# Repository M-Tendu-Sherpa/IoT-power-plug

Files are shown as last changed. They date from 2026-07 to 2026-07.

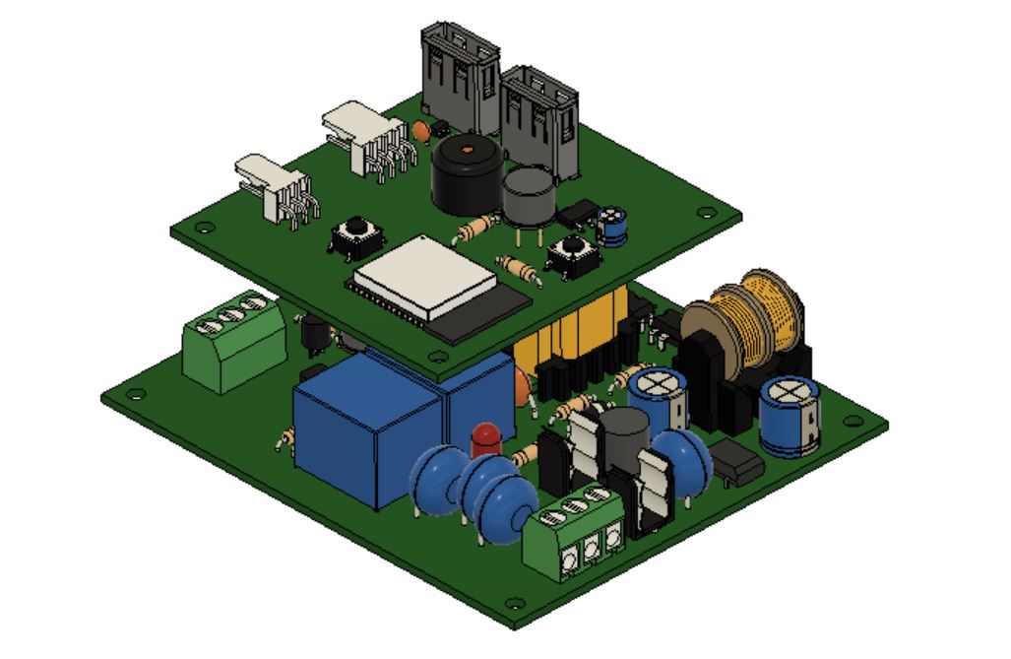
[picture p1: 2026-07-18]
Render images 3D/PCB_assembly.JPG

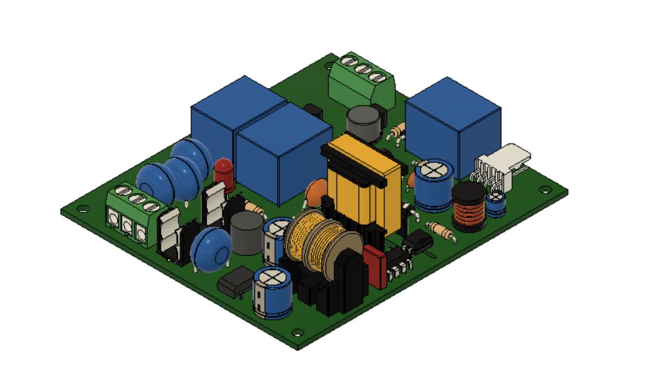
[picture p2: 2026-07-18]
Render images 3D/Bottom_PCB.JPG

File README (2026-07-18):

This project was done as a freelance project where I was paid to design the electrical aspects for the IoT smart plug,
which included schematics, component selection, BOM, PCB design, and 3D design.
The circuit is designed to fetch the weather data from the internet and monitor the lightening hazard.
Under severe weather conditions the plug would disconned the power from all the appliances connected through it,
hence ensuring electrical safety.

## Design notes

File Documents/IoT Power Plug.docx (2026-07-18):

IoT Power Plug

The IoT power plug with the ESP32 chip ensures protection of the devices connected to its extensions. The extensions included supports two 110VAC and 5VDC based devices each.

The ESP32 chip works with both WiFi and Bluetooth Low Energy (BLE) and is more stable and advanced than any other IoT microcontrollers. Here in this product, the ESP32 WROOM 32 chip suits best considering all our requirements. The overall product is equipped with surge protector (triple MOV configuration) and a FUSE to ensure superior safety. Similarly, when the ESP turns off the power supply to the extension plugs, the relay configuration completely isolates the devices connected to the extension from the main power line. The power plug also includes a buzzer module controlled by the ESP chip and a 15 Watt DC power supply to power the overall control system and the 5VDC power extension.

Block Diagram

Signal flow

Power flow

To extension

110V AC

Buzzer Module

ESP32

Relay Module

Surge Protection

SMPS 15W

3.3V Regulator

Schematic diagram

The PCB is designed in two layers: the bottom layer and the top layer. The significance of this design method is to isolate the AC circuits from the delicate DC circuits. Besides that, stacking the PCB one above another serves for compact design of the product. The schematic of each layer is shown below with the description of the functional units it includes.

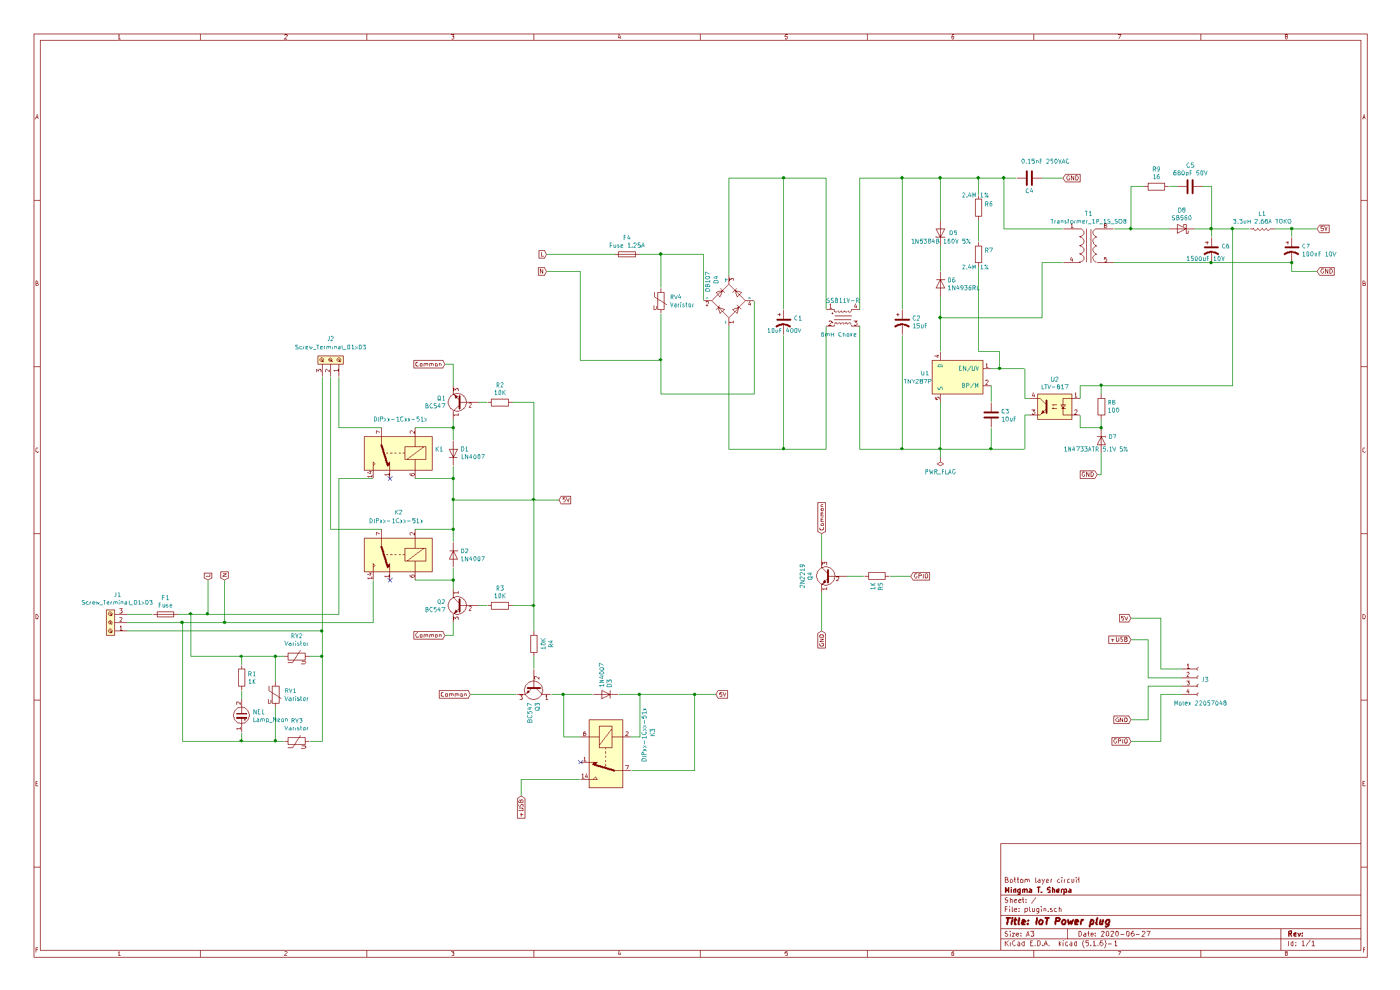
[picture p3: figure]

FIG: Schematic of the bottom layer PCB

The above schematic includes the following functional units:

1. Triple surge protection with FUSE
2. Relay configuration for switching the power to extensions
3. 15W SMPS DC power supply
4. Connectors for power and ESP32.

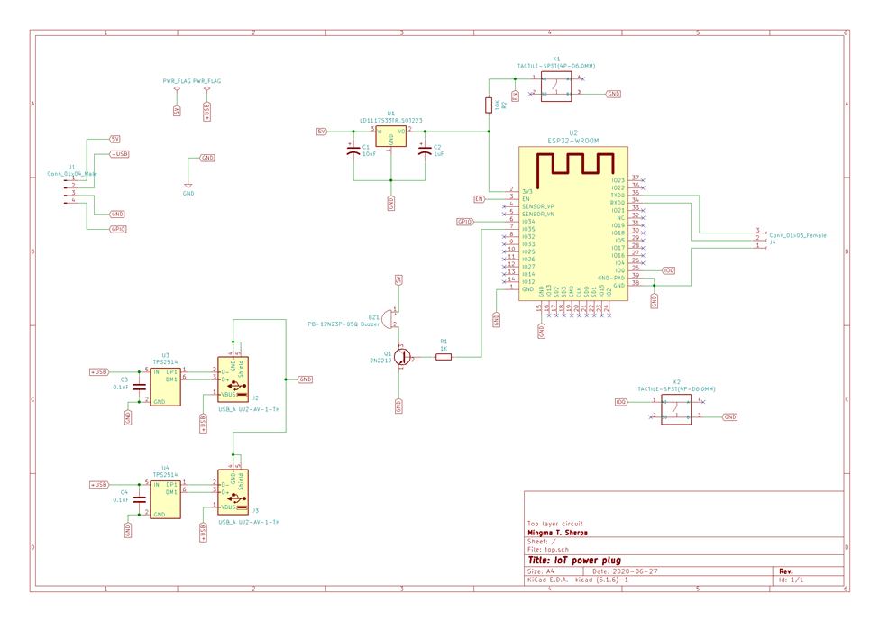
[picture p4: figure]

FIG: Schematic of the top layer PCB

The above schematic includes the following functional units:

1. ESP32
2. 3.3V DC power regulator for ESP32
3. Two 5VDC USB outlets
4. Buzzer module
5. Connectors for power and ESP32

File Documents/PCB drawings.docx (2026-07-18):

DRAWINGS

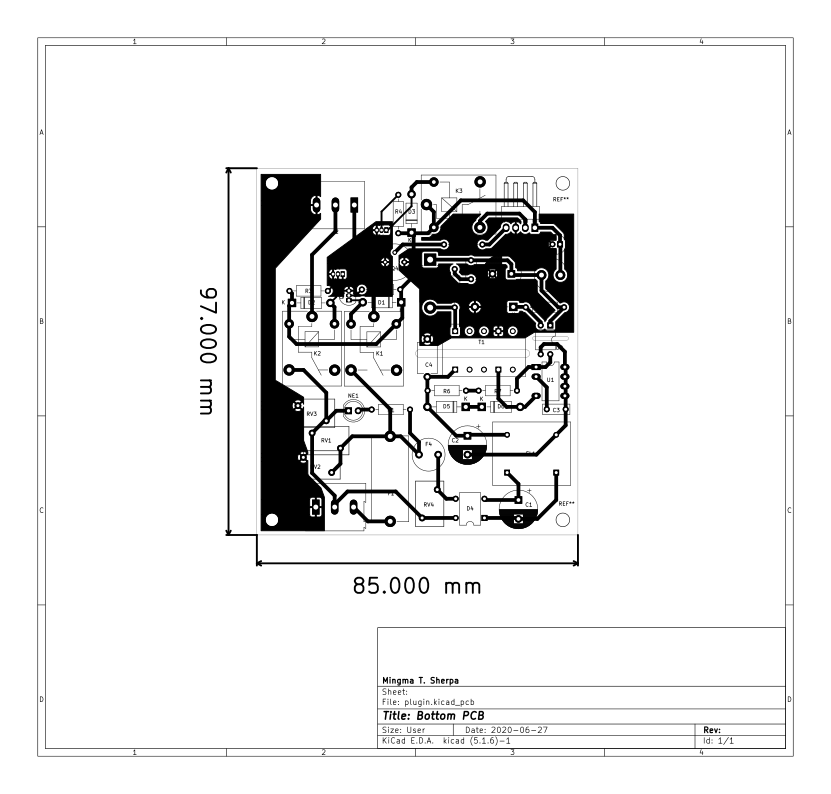
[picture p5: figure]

Fig 1.1: Bottom layer PCB layout

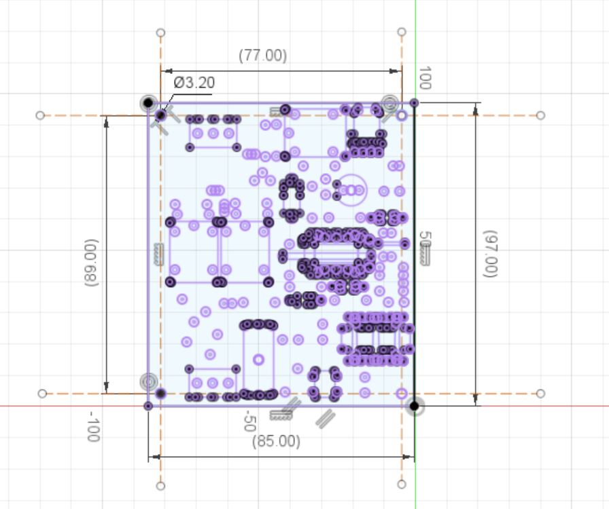
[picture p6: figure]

Fig 1.2: Bottom layer PCB dimensions

Above figures includes dimensions of the board along with edge cuts and drill holes. The drill holes are made compatible for M3 screws.

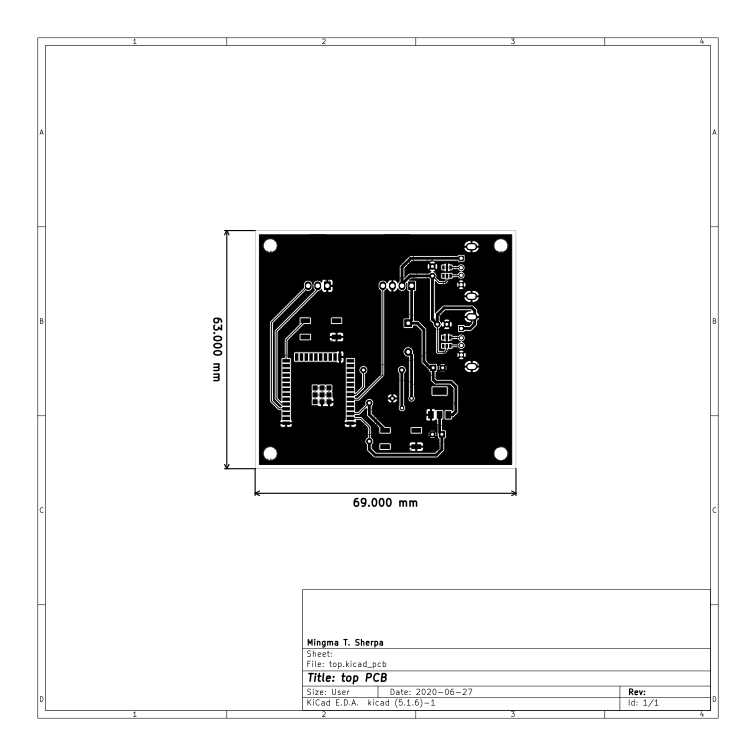
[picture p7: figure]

Fig 2.1: Top layer PCB layout

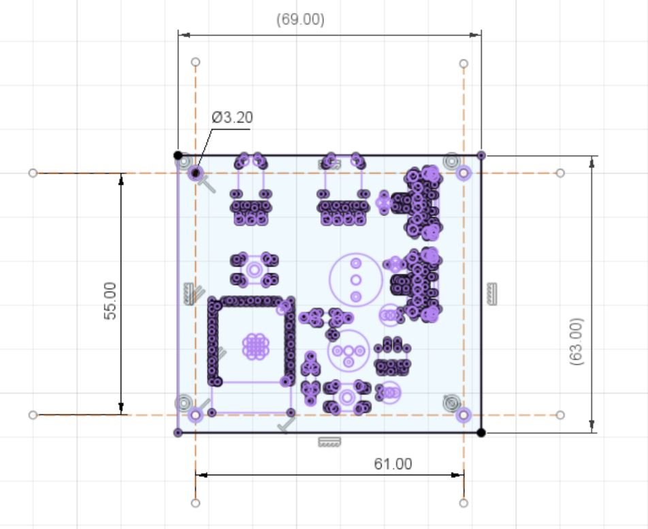
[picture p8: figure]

Fig 2.2: Top layer PCB dimensions

Above figures includes the dimensions of the board with all necessary masks (similar in Fig 1). The screw used are the M3 standard as in Bottom layer PCB.

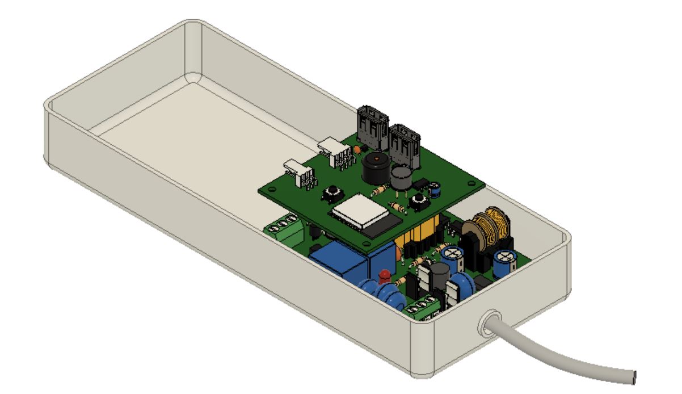
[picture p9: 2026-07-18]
Render images 3D/Within_case1.JPG

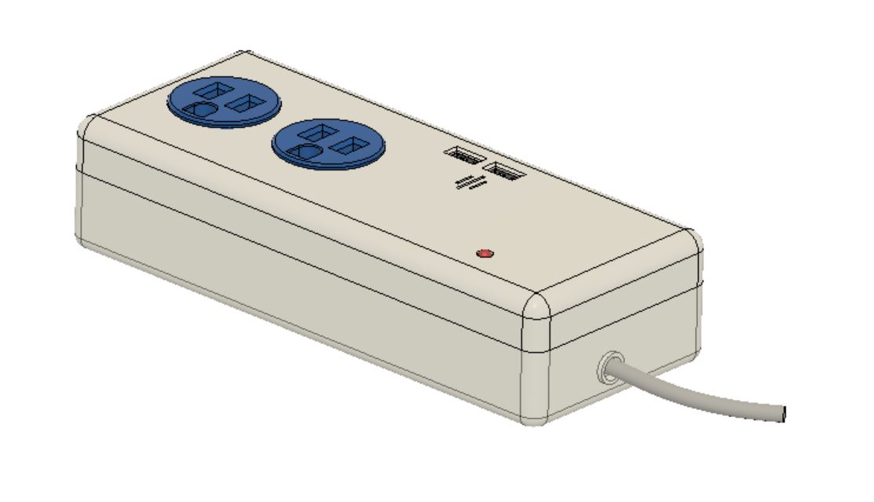
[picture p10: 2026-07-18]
Render images 3D/Within_case2.JPG

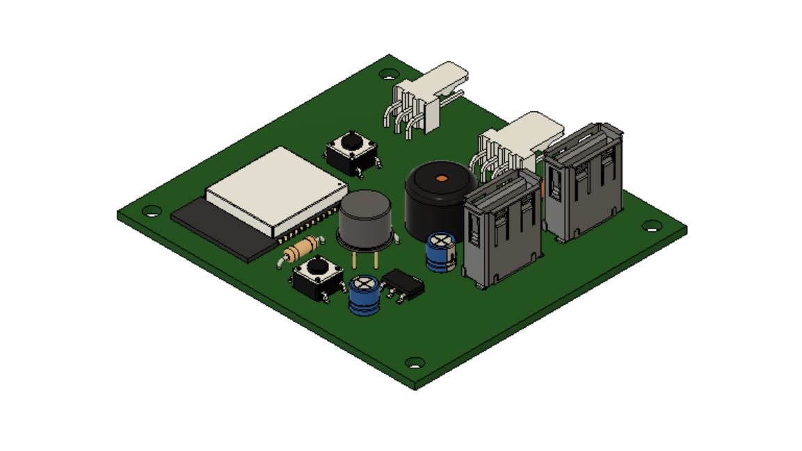
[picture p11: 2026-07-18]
Render images 3D/Top_PCB.JPG

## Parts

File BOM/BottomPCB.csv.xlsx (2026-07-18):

Source: | Bottom layer circuit
Date: | 2020-06-27 11:53
Tool: | Eeschema (5.1.6)-1
Component Count: | 46
Ref | Value | Footprint | Datasheet | Manufacturer | Vendor
C1 | 10uF 400V | Capacitor_THT:CP_Radial_D10.0mm_P5.00mm | ~
C2 | 15uF | Capacitor_THT:CP_Radial_D10.0mm_P5.00mm | ~
C3 | 10uF | Capacitor_THT:C_Rect_L7.0mm_W2.5mm_P5.00mm | ~
C4 | 0.15nF 250VAC | Capacitor_THT:C_Disc_D8.0mm_W5.0mm_P10.00mm | ~
C5 | 680pF 50V | Capacitor_THT:C_Disc_D5.0mm_W2.5mm_P5.00mm | ~
C6 | 1500uF 10V | Capacitor_THT:CP_Radial_D10.0mm_P5.00mm | ~
C7 | 100uF 10V | Capacitor_THT:CP_Radial_D5.0mm_P2.00mm | ~
D1 | 1N4007 | Diode_THT:D_DO-41_SOD81_P10.16mm_Horizontal | http://www.vishay.com/docs/88503/1n4001.pdf
D2 | 1N4007 | Diode_THT:D_DO-41_SOD81_P10.16mm_Horizontal | http://www.vishay.com/docs/88503/1n4001.pdf
D3 | 1N4007 | Diode_THT:D_DO-41_SOD81_P10.16mm_Horizontal | http://www.vishay.com/docs/88503/1n4001.pdf
D4 | DB107 | Diode_THT:Diode_Bridge_DIP-4_W7.62mm_P5.08mm | https://diotec.com/tl_files/diotec/files/pdf/datasheets/b40c2300.pdf
D5 | 1N5384B 160V 5% | Diode_THT:D_DO-41_SOD81_P10.16mm_Horizontal | ~
D6 | 1N4936RL | Diode_THT:D_DO-41_SOD81_P10.16mm_Horizontal | ~
D7 | 1N4733ATR 5.1V 5% | Diode_THT:D_DO-41_SOD81_P10.16mm_Horizontal | ~
D8 | SB560 | Diode_THT:D_DO-201AD_P12.70mm_Horizontal | ~
F1 | Fuse Holder | Fuse:Fuseholder_Cylinder-5x20mm_Schurter_0031_8201_Horizontal_Open | ~
F4 | Fuse 1.25A | Fuse:Fuse_Littelfuse_372_D8.50mm | ~
J1 | Screw_Terminal_01x03 | TerminalBlock:TerminalBlock_Altech_AK300-3_P5.00mm | ~
J2 | Screw_Terminal_01x03 | TerminalBlock:TerminalBlock_Altech_AK300-3_P5.00mm | ~
J3 | Molex 22057048 | footprints:Molex_KK-254_1x04_P2.54mm_Horizontal | ~
K1 | DIPxx-1Cxx-51x | Relay_THT:Relay_SPDT_SANYOU_SRD_Series_Form_C | https://standexelectronics.com/wp-content/uploads/datasheet_reed_relay_DIP.pdf
K2 | DIPxx-1Cxx-51x | Relay_THT:Relay_SPDT_SANYOU_SRD_Series_Form_C | https://standexelectronics.com/wp-content/uploads/datasheet_reed_relay_DIP.pdf
K3 | DIPxx-1Cxx-51x | Relay_THT:Relay_SPDT_SANYOU_SRD_Series_Form_C | https://standexelectronics.com/wp-content/uploads/datasheet_reed_relay_DIP.pdf
L1 | 3.3uH 2.66A TOKO | Inductor_THT:L_Radial_D8.7mm_P5.00mm_Fastron_07HCP | ~
NE1 | Lamp_Neon | LED_THT:LED_D5.0mm | ~
Q1 | BC547 | Package_TO_SOT_THT:TO-92_Inline | http://www.fairchildsemi.com/ds/BC/BC547.pdf
Q2 | BC547 | Package_TO_SOT_THT:TO-92_Inline | http://www.fairchildsemi.com/ds/BC/BC547.pdf
Q3 | BC547 | Package_TO_SOT_THT:TO-92_Inline | http://www.fairchildsemi.com/ds/BC/BC547.pdf
Q4 | 2N2219 | Package_TO_SOT_THT:TO-39-3 | http://www.onsemi.com/pub_link/Collateral/2N2219-D.PDF
R1 | 1K | Resistor_THT:R_Axial_DIN0207_L6.3mm_D2.5mm_P10.16mm_Horizontal | ~
R2 | 10K | Resistor_THT:R_Axial_DIN0207_L6.3mm_D2.5mm_P10.16mm_Horizontal | ~
R3 | 10K | Resistor_THT:R_Axial_DIN0207_L6.3mm_D2.5mm_P10.16mm_Horizontal | ~
R4 | 10K | Resistor_THT:R_Axial_DIN0207_L6.3mm_D2.5mm_P10.16mm_Horizontal | ~
R5 | 1K | Resistor_THT:R_Axial_DIN0207_L6.3mm_D2.5mm_P10.16mm_Horizontal | ~
R6 | 2.4M 1% | Resistor_THT:R_Axial_DIN0207_L6.3mm_D2.5mm_P10.16mm_Horizontal | ~
R7 | 2.4M 1% | Resistor_THT:R_Axial_DIN0207_L6.3mm_D2.5mm_P10.16mm_Horizontal | ~
R8 | 100 | Resistor_THT:R_Axial_DIN0207_L6.3mm_D2.5mm_P10.16mm_Horizontal | ~
R9 | 16 | Resistor_THT:R_Axial_DIN0207_L6.3mm_D2.5mm_P10.16mm_Horizontal | ~
RV1 | Varistor | Varistor:RV_Disc_D12mm_W7.5mm_P7.5mm | ~
RV2 | Varistor | Varistor:RV_Disc_D12mm_W7.5mm_P7.5mm | ~
RV3 | Varistor | Varistor:RV_Disc_D12mm_W7.5mm_P7.5mm | ~
RV4 | Varistor | Varistor:RV_Disc_D12mm_W7.5mm_P7.5mm | ~
SSB11V-R1 | 6mH Choke | Inductor_THT:6mH choke Kemet | ~
T1 | Transformer_1P_1S_SO8 | Transformer_THT:EPCOS B66311-G-X127 | ~
U1 | TNY287P | Package_DIP:PowerIntegrations_PDIP-8C | https://ac-dc.power.com/sites/default/files/product-docs/tinyswitch-4_family_datasheet.pdf
U2 | LTV-817 | Package_DIP:DIP-4_W7.62mm | http://www.us.liteon.com/downloads/LTV-817-827-847.PDF

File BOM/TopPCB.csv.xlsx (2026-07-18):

Source: | Top layer PCB
Date: | 2020-06-27 12:05
Tool: | Eeschema (5.1.6)-1
Component Count: | 18
Ref | Value | Footprint | Datasheet | Manufacturer | Vendor
BZ1 | PB-12N23P-05Q Buzzer | Buzzer_Beeper:Buzzer_12x9.5RM7.6 | ~
C1 | 10uF | Capacitor_THT:CP_Radial_D5.0mm_P2.50mm | ~
C2 | 1uF | Capacitor_THT:CP_Radial_D5.0mm_P2.50mm | ~
C3 | 0.1uF | Capacitor_THT:C_Disc_D3.8mm_W2.6mm_P2.50mm | ~
C4 | 0.1uF | Capacitor_THT:C_Disc_D3.8mm_W2.6mm_P2.50mm | ~
J1 | Conn_01x04_Male | footprints:Molex_KK-254_1x04_P2.54mm_Horizontal | ~
J2 | USB_A UJ2-AV-1-TH | Connector_USB:USB_A_Molex_105057_Vertical | ~
J3 | USB_A UJ2-AV-1-TH | Connector_USB:USB_A_Molex_105057_Vertical | ~
J4 | Conn_01x03_Female | footprints:Molex_KK-254_1x03_P2.54mm_Horizontal | ~
K1 | TACTILE-SPST(4P-D6.0MM) | DTSM tactile SMB switch:SW4-SMD-6.0X6.0X5.0MM | DTSM-62K-S-V-T/R
K2 | TACTILE-SPST(4P-D6.0MM) | DTSM tactile SMB switch:SW4-SMD-6.0X6.0X5.0MM | DTSM-62K-S-V-T/R
Q1 | 2N2219 | Package_TO_SOT_THT:TO-39-3 | http://www.onsemi.com/pub_link/Collateral/2N2219-D.PDF
R1 | 1K | Resistor_THT:R_Axial_DIN0207_L6.3mm_D2.5mm_P10.16mm_Horizontal | ~
R2 | 10K | Resistor_THT:R_Axial_DIN0207_L6.3mm_D2.5mm_P10.16mm_Horizontal | ~
U1 | LD1117S33TR_SOT223 | Package_TO_SOT_SMD:SOT-223-3_TabPin2 | http://www.st.com/st-web-ui/static/active/en/resource/technical/document/datasheet/CD00000544.pdf
U2 | ESP32-WROOM | ESP32:MODULE_ESP32-WROOM-32
U3 | TPS2514 | Package_TO_SOT_SMD:SOT-23-6 | http://www.ti.com/lit/ds/symlink/tps2513.pdf
U4 | TPS2514 | Package_TO_SOT_SMD:SOT-23-6 | http://www.ti.com/lit/ds/symlink/tps2513.pdf
